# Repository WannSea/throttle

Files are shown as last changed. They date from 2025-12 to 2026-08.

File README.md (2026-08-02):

# WannSea Gashebel Firmware

Dieses Projekt nutzt das https://github.com/rp-rs/rp2040-project-template als Template.

## Installation

Rust über https://rustup.rs/ installieren und anschließend ausführen:

```sh
rustup target install thumbv6m-none-eabi
cargo install flip-link
cargo install --locked elf2uf2-rs
```

## Build

Es gibt zwei Möglichkeiten:

1. Den RP2040 mit gedrückter BOOTSEL-Taste per USB verbinden und die Firmware direkt bauen und flashen:

   ```sh
   cargo run
   ```

2. Eine UF2-Datei bauen, die später manuell auf das RP2040-USB-Laufwerk kopiert werden kann:

   ```sh
   cargo build --release
   elf2uf2-rs target/thumbv6m-none-eabi/release/rp2040-project-template throttle.uf2
   ```

## Info:

Green LED Blinking: Sending CAN throttle command
Red LED: Lever Locked

## Encoder / Hall

Der verwendete Encoder mit dem 5-poligen Stecker ist ein AS5600 und wird über I2C gelesen:

- Board-Stecker: `SDA`, `SCL`, `PWM/OUT`, `GND`, `3V3`
- Am AS5600: `VCC -> 3V3`, `GND -> GND`, `SDA -> SDA`, `SCL -> SCL`
- `DIR` habe ich fest mit `VCC` verbunden.
- `OUT/PWM` wird von der Firmware aktuell nicht benutzt.

## Veränderbare Parameter

Die wichtigsten Parameter stehen am Anfang von `src/main.rs`:

- `MAX_CURRENT_A`: maximal ausgegebener Strom bei vollständig ausgelenktem Gashebel, aktuell `500.0` A.
- `DELAY_MS`: Zeit zwischen zwei Ausgaben. `20` ms entsprechen 50 Hz.
- `ENCODER_ZERO_RAW`: Raw-Wert des Encoders in der neutralen Hebelposition.
- `ENCODER_FORWARD_MAX_RAW`: Raw-Wert bei vollständig nach vorne gedrücktem Gashebel.
- `ENCODER_REVERSE_MAX_RAW`: Raw-Wert bei vollständig nach hinten gedrücktem Gashebel.
- `ENCODER_DEADZONE_COUNTS`: Totzone von der Neutralstellung aus in jede Richtung. `50` bedeutet ungefähr 100 Counts Gesamttotzone.
- `PRETEND_HALL_PIN_ON`: Bei `true` wird der Hall-/Kill-Cord-Eingang für Tests als dauerhaft vorhanden behandelt.
- `ENABLE_USB_LOGGING`: Aktiviert bei `true` die Ausgabe der Encoderwerte über USB-Serial.

Die Encoder-Endwerte dürfen je nach Einbaurichtung des Sensors größer oder kleiner als `ENCODER_ZERO_RAW` sein. Entscheidend ist, dass die Werte an den tatsächlichen Endpositionen des Hebels eingetragen werden.

## USB-Debug-Ausgabe

Bei aktiviertem `ENABLE_USB_LOGGING` wird beispielsweise folgende Zeile ausgegeben:

```text
encoder raw: 2237, throttle_milli: 0, can: 00000116#00000000
```

Die drei Werte bedeuten:

- `encoder raw`: unverarbeiteter 12-Bit-Messwert des AS5600 von `0` bis `4095`.
- `throttle_milli`: aus Kalibrierung und Totzone berechnete Gasstellung. `-1000` entspricht dem einen Endanschlag, `0` der Neutralstellung und `+1000` dem anderen Endanschlag.
- `can`: Vorschau der tatsächlich gesendeten CAN-Nachricht im Format `CAN-ID#Payload`. `00000116` ist die `SetCurrent`-Nachricht für VESC-ID 22. Der achtstellige Payload enthält den vorzeichenbehafteten Stromwert als Ampere × 1.000. Im gesperrten Zustand ist dieser Payload immer `00000000`.

## SetDuty- und SetCurrent-Version

| SetDuty-Version | Aktuelle SetCurrent-Version |
|---|---|
| VESC `SetDuty`, CAN-ID `0x16` | VESC `SetCurrent`, CAN-ID `0x116` |
| Payload: vorzeichenbehafteter Duty-Wert von −100.000 bis +100.000 | Payload: vorzeichenbehafteter Stromwert von −500.000 bis +500.000 (Ampere × 1.000) |
| 50 Werte großes Glättungsfenster | Keine Glättung und keine Rampe |
| Vollständige Rampe dauert ca. 1 Sekunde | Ausgang folgt dem Gashebel unmittelbar |
| Ausgabe alle 20 ms / 50 Hz | Ausgabe alle 20 ms / 50 Hz |
| Null und der gesperrte Zustand werden explizit gesendet | Null und der gesperrte Zustand werden explizit gesendet |
| Encoder- und Hall-Auswertung wie in der aktuellen Version | Encoder- und Hall-Auswertung unverändert |

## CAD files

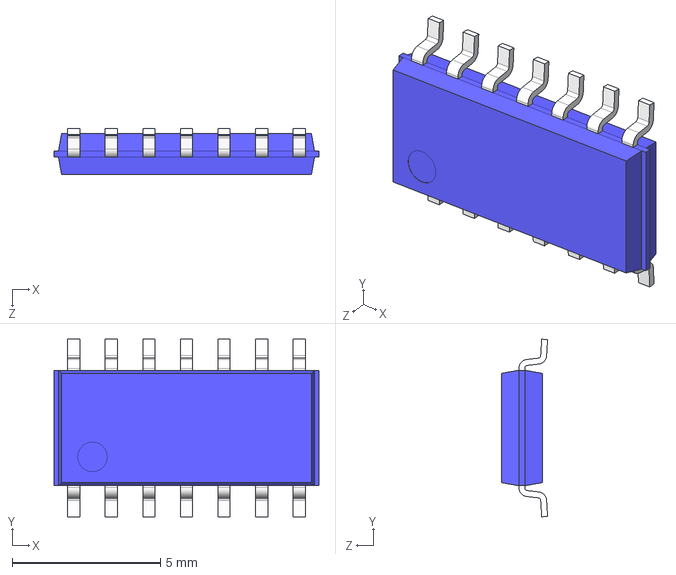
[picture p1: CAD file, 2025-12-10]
gashebel/1C23_powertrain_3D_models/SOIC14.STEP
8.95 x 6.00 x 1.56 mm

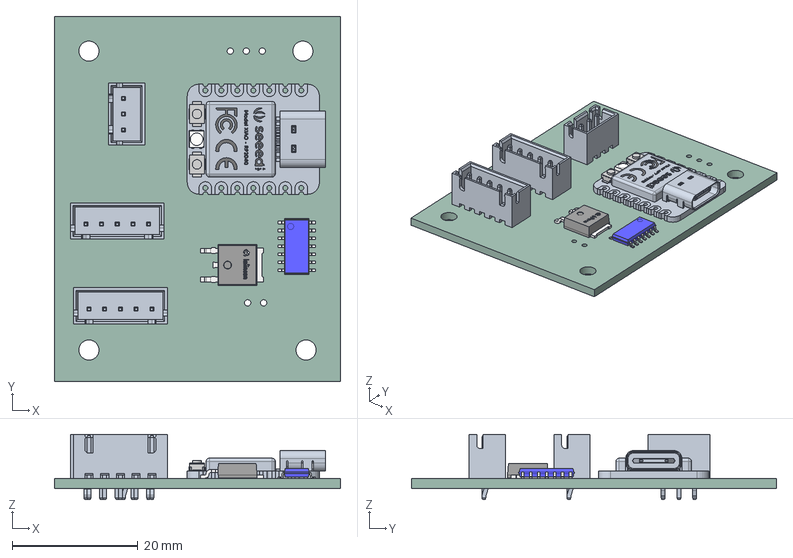
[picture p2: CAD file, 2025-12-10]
gashebel/gashebelboard.step
45.5 x 58.0 x 10.4 mm
B5B-XH-A x 2
B3B-XH-A
Product
Seeed Studio XIAO RP2040 v26
SOIC14
gashebelboard_PCB

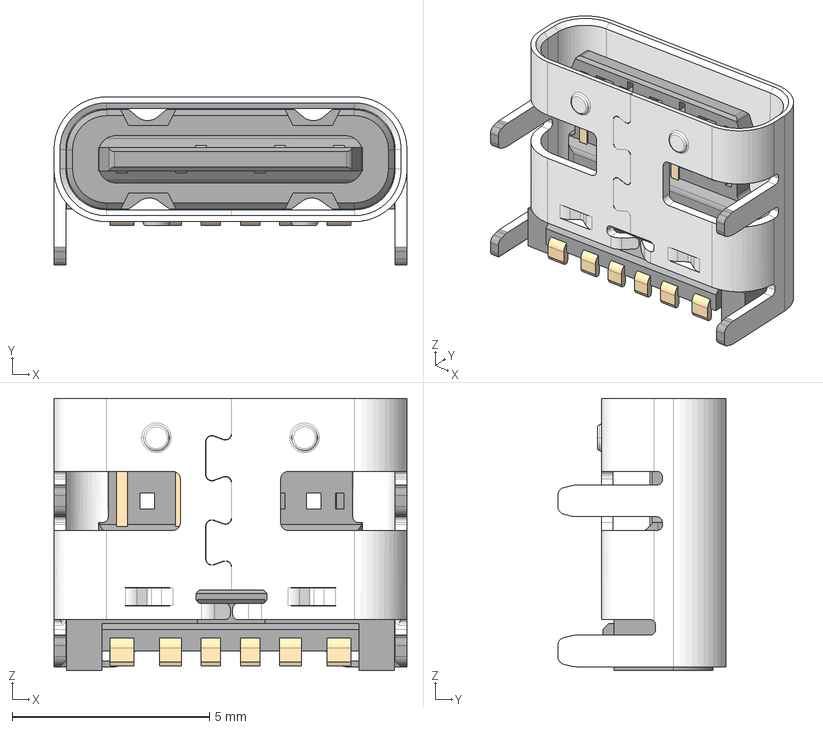
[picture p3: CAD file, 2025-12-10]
gashebel/1C23_powertrain_3D_models/USB4125-GF-A.stp
8.94 x 4.26 x 6.90 mm

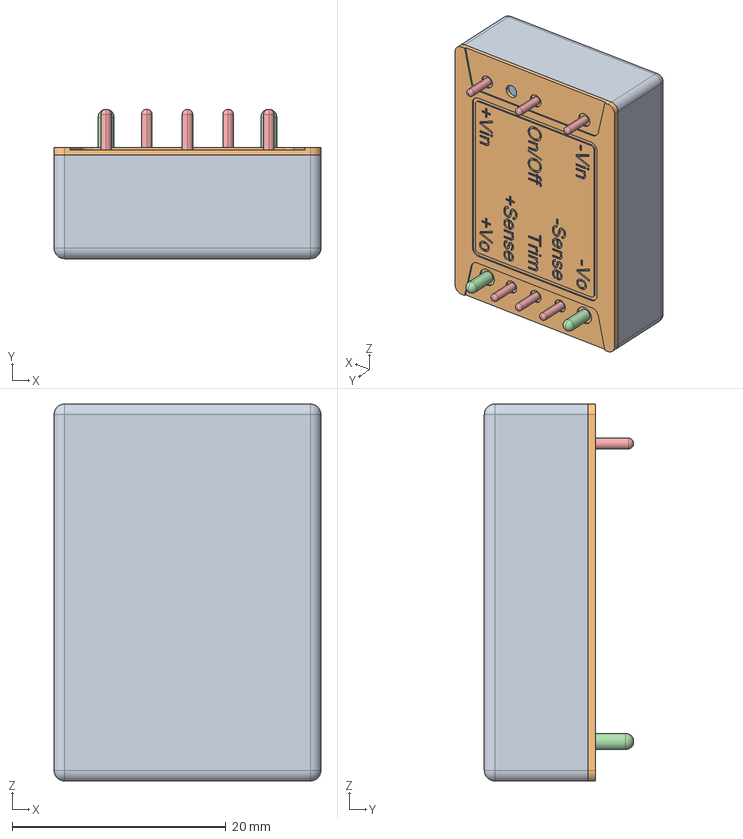
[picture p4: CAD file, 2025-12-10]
gashebel/1C23_powertrain_3D_models/PKU5500S.stp
25.0 x 14.0 x 35.3 mm
CU-CASE
BASE-PLASTIC
PCB
PIN1-2 x 2
PIN1-1 x 6

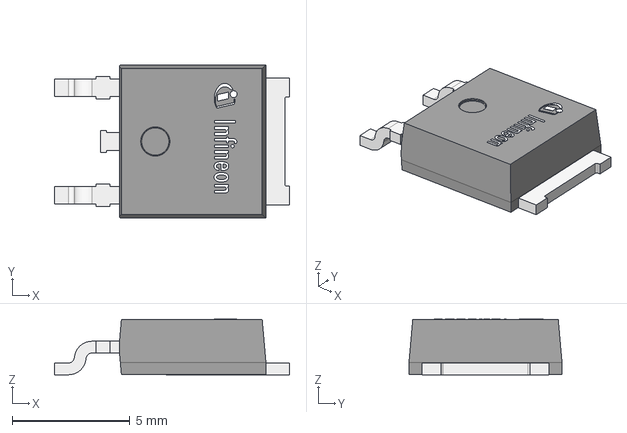
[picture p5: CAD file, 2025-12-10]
gashebel/1C23_powertrain_3D_models/Infineon-PG-TO252-3-11_3D_01_STP-Package-v05_00-EN.stp
9.98 x 6.50 x 2.36 mm

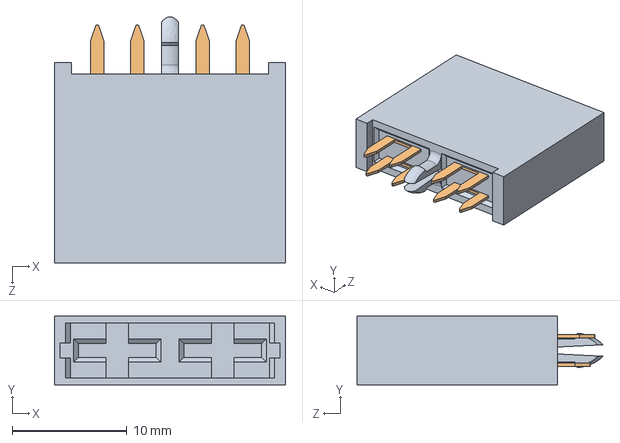
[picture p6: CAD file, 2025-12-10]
gashebel/1C23_powertrain_3D_models/178.6165.0000---Holder-FLR-(ATO)-Step-model.step
20.1 x 6.00 x 21.5 mm

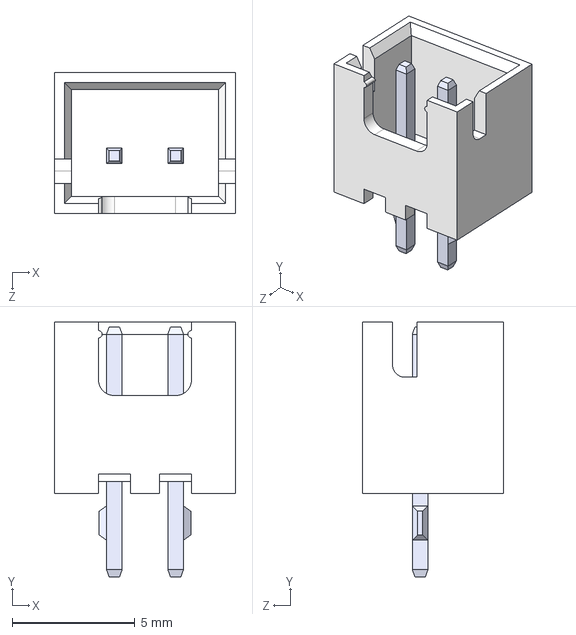
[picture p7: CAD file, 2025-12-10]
gashebel/1C23_powertrain_3D_models/B2B-XH-A.step
7.40 x 10.4 x 5.75 mm

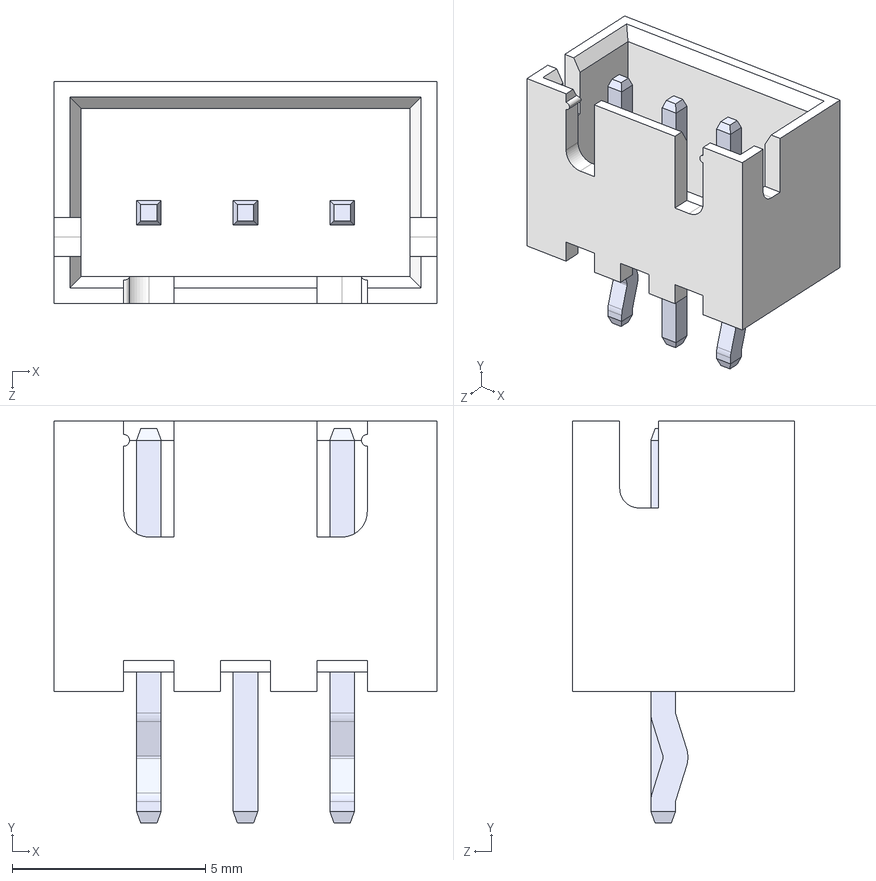
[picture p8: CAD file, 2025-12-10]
gashebel/1C23_powertrain_3D_models/B3B-XH-A.step
9.90 x 10.4 x 5.75 mm

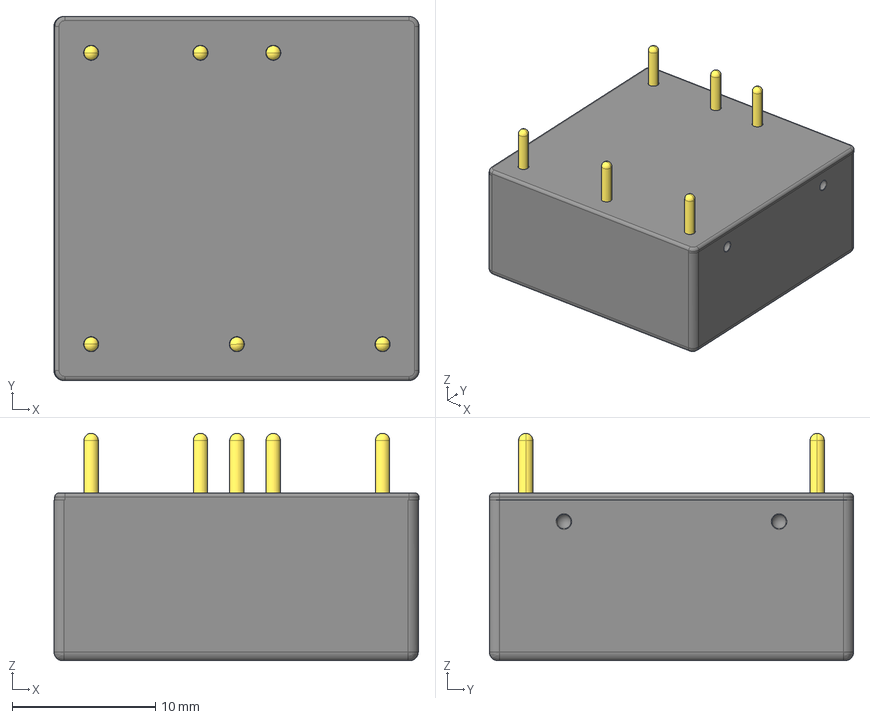
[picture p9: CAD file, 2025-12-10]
gashebel/1C23_powertrain_3D_models/URB_YMD-20WR3.stp
25.5 x 25.4 x 15.9 mm
MANIFOLD_SOLID_BREP_442_1
MANIFOLD_SOLID_BREP_826_1
MANIFOLD_SOLID_BREP_1210_1
MANIFOLD_SOLID_BREP_1594_1
MANIFOLD_SOLID_BREP_1978_1 x 2
MANIFOLD_SOLID_BREP_9091_1

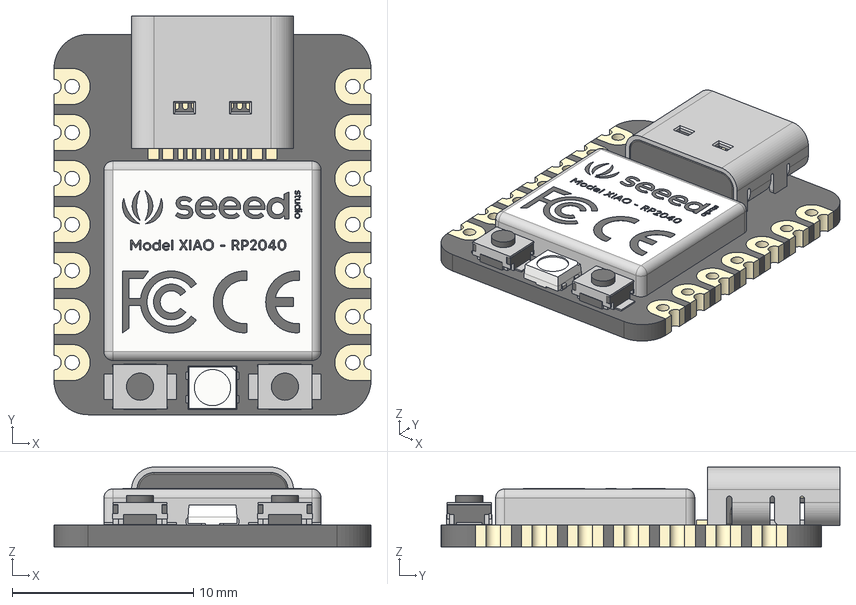
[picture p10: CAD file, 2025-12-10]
gashebel/1C23_powertrain_3D_models/Seeed Studio XIAO RP2040 v26.step
17.5 x 22.0 x 4.40 mm
type-c v2
smd_button v3
DOUT
DIN
VSS
VDD
smd_button v3(Mirror)

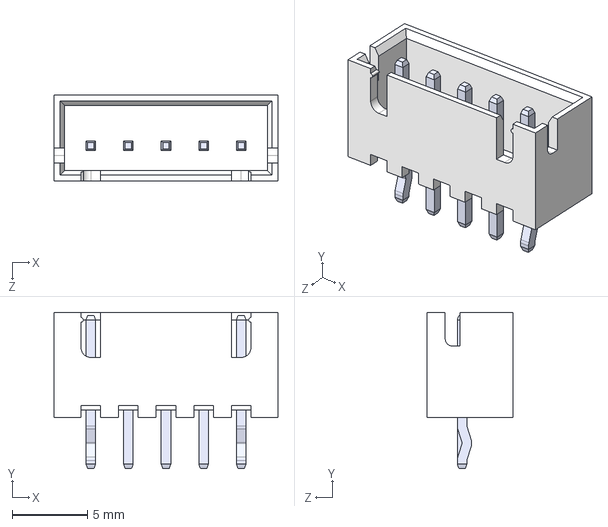
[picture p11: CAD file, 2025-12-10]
gashebel/1C23_powertrain_3D_models/B5B-XH-A.step
14.9 x 10.4 x 5.75 mm

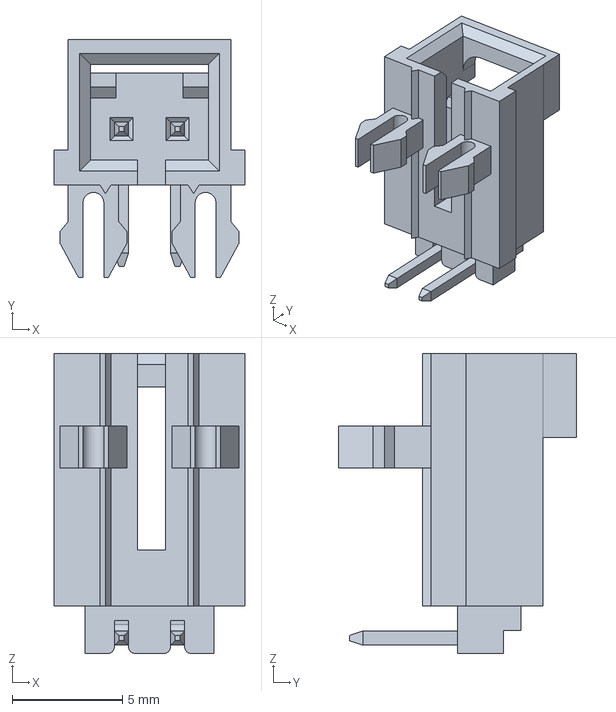
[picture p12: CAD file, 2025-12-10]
gashebel/1C23_powertrain_3D_models/705510036.stp
8.63 x 10.8 x 13.6 mm

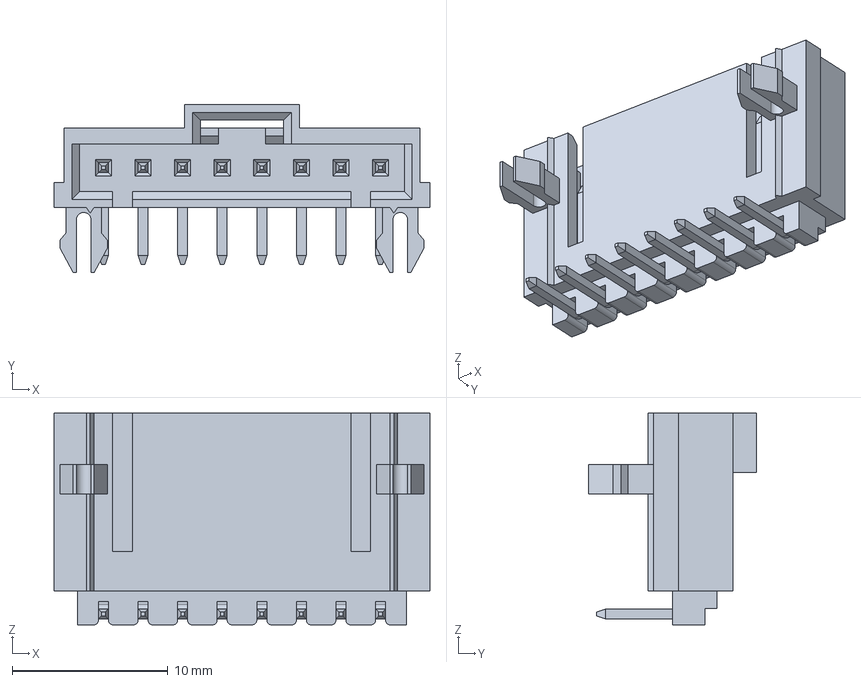
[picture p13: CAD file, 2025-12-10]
gashebel/1C23_powertrain_3D_models/705510042.stp
24.1 x 10.8 x 13.6 mm

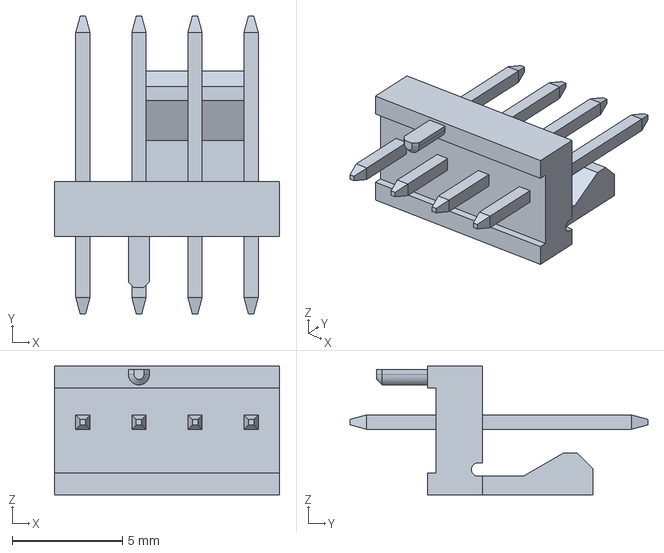
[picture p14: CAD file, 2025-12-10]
gashebel/1C23_powertrain_3D_models/470531000.stp
10.2 x 13.5 x 5.84 mm

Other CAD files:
gashebel/1C23_powertrain_3D_models/2741400000.stp
gashebel/1C23_powertrain_3D_models/705510038.stp
gashebel/1C23_powertrain_3D_models/705510037.stp
gashebel/1C23_powertrain_3D_models/705510040.stp

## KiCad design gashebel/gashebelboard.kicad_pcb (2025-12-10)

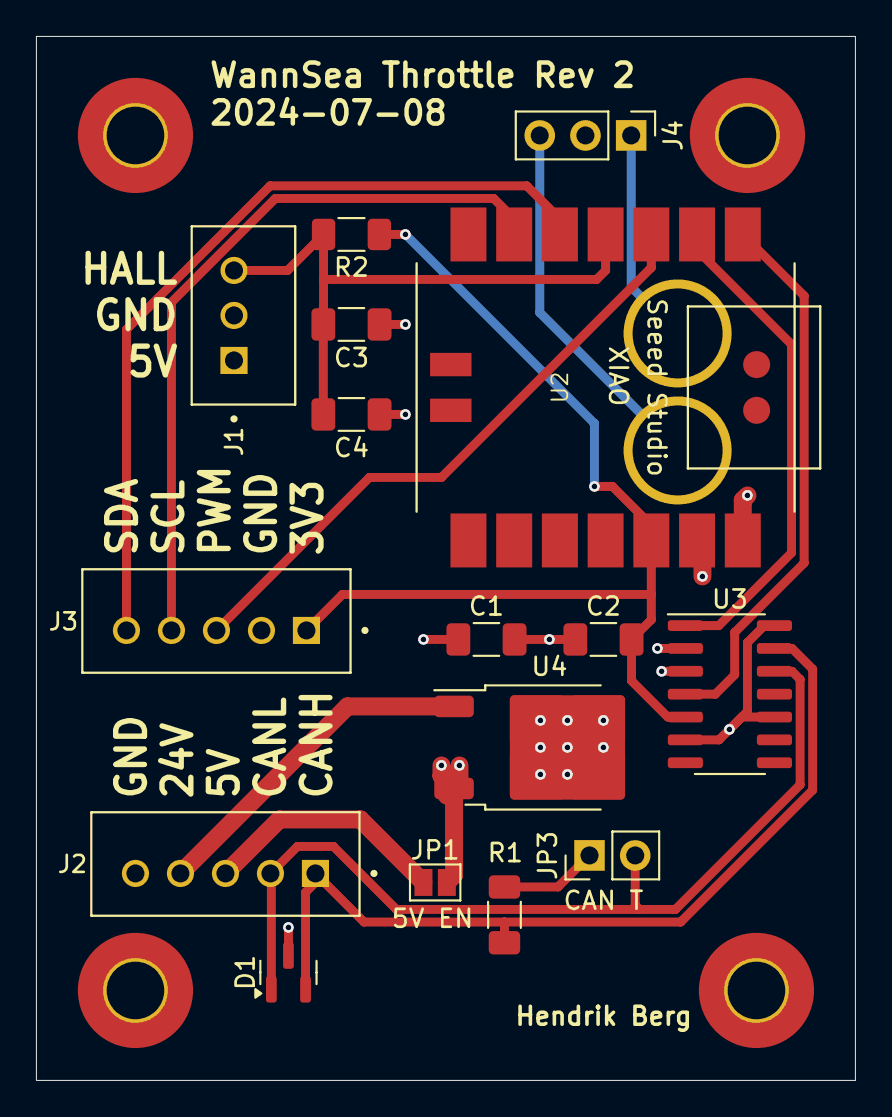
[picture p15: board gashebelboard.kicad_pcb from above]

Board: 4 copper layers, 45.5 x 58.0 mm, 20 parts (0 on the bottom side), 16 nets.

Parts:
C1, C2: 10µ; C_1206_3216Metric_Pad1.33x1.80mm_HandSolder
C3, C4: 4.7nF; C_1206_3216Metric_Pad1.33x1.80mm_HandSolder
D1: SM712_SOT23; SOT-23
H1, H2, H3, H4: MountingHole_Pad; MountingHole_3.2mm_M3_Pad_TopBottom
J1: Hall; JST_B3B-XH-A
J2: BOOT BUS; JST_B5B-XH-A
J3: ENCODER; JST_B5B-XH-A
J4: Conn_01x03_Pin; PinHeader_1x03_P2.54mm_Vertical
JP1: 5V EN; SolderJumper-2_P1.3mm_Open_Pad1.0x1.5mm
JP3: CAN T; PinHeader_1x02_P2.54mm_Vertical
R1: 120; R_1206_3216Metric_Pad1.30x1.75mm_HandSolder
R2: 1.2K; R_1206_3216Metric_Pad1.30x1.75mm_HandSolder
U2: Seeed Studio XIAO SAMD21; XIAO-SAMD21-RP2040-14P-2.54-21X17.8MM (Seeeduino XIAO)
U3: TJA1043T; SOIC-14_3.9x8.7mm_P1.27mm
U4: LM78M05_TO252; TO-252-2

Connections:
+3.3V: C2.2, J3.1, R2.1, U2.12 (3V3), U3.5 (VIO)
+5V: C1.1, C3.1, J1.1, JP1.2 (B), U2.14 (5V), U3.3 (VCC), U3.6 (EN), U3.10 (VBAT), U3.14 (~STB), U4.3 (VO)
/CAN_RX: U2.1 (PA02_A0_D0), U3.4 (RXD)
/CAN_TX: U2.2 (PA4_A1_D1), U3.1 (TXD)
/HALL: C3.2, C4.2, J1.3, R2.2, U2.4 (PA11_A3_D3)
/PWM: J3.3, U2.3 (PA10_A2_D2)
/SCL: J3.4, U2.6 (PA9_A5_D5_SCL)
/SDA: J3.5, U2.5 (PA8_A4_D4_SDA)
GND: C1.2, C2.1, C4.1, D1.3 (common), H1.1, H2.1, H3.1, H4.1, J1.2, J2.5, J3.2, J4.2, U2.13 (GND), U3.2 (GND), U4.2 (GND)
unnamed: D1.1 (A1), J2.2, JP3.2 (B), U3.12 (CANL)
unnamed: D1.2 (A2), J2.1, R1.1, U3.13 (CANH)
unnamed: J2.3, JP1.1 (A)
unnamed: J2.4, U4.1 (VI)
unnamed: J4.1, U2.17 (PA31_SWDIO)
unnamed: J4.3, U2.18 (PA30_SWCLK)
unnamed: JP3.1 (A), R1.2

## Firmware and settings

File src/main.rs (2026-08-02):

#![no_std]
#![no_main]

use alloc_cortex_m::CortexMHeap;
use bsp::entry;
use can2040::{Can2040, CanFrame};
use core::fmt::Write;
use defmt::*;
use defmt_rtt as _;
use embedded_can::nb::Can;
use embedded_can::{ExtendedId, Frame};
use embedded_hal::delay::DelayNs;
use embedded_hal::digital::{InputPin, OutputPin};
use embedded_hal::i2c::I2c;
use heapless::String;
use panic_probe as _;
use usb_device::{
    class_prelude::UsbBusAllocator,
    device::{StringDescriptors, UsbDevice},
    prelude::*,
};
use usbd_serial::SerialPort;

use seeeduino_xiao_rp2040 as bsp;

const CONFIG_CANBUS_FREQUENCY: u32 = 250_000;
const CONFIG_RP2040_CANBUS_GPIO_RX: u32 = 26;
const CONFIG_RP2040_CANBUS_GPIO_TX: u32 = 27;
const ENABLE_USB_LOGGING: bool = true;

#[global_allocator]
pub static ALLOCATOR: CortexMHeap = CortexMHeap::empty();

pub fn init_allocator() {
    // Please set the correct heap size.
    const HEAP_SIZE: usize = 0x8000;
    static mut HEAP: [u8; HEAP_SIZE] = [0; HEAP_SIZE];
    unsafe { ALLOCATOR.init(HEAP.as_ptr() as usize, HEAP.len()) }
}

use bsp::hal::{
    clocks::init_clocks_and_plls,
    fugit::RateExtU32,
    gpio::{FunctionI2C, Pin},
    pac,
    sio::Sio,
    usb::UsbBus,
    watchdog::Watchdog,
    Timer, I2C,
};

#[allow(dead_code)]
#[repr(u8)]
enum CanCommands {
    SetDuty = 0,
    SetCurrent = 1,
    SetCurrentBrake = 2,
    SetRpm = 3,
    SetPos = 4,
}

const VESC_ID: u32 = 22;
const CAN_ID_SET_CURRENT_RAW: u32 = (CanCommands::SetCurrent as u32) << 8 | VESC_ID;
const CAN_ID_SET_CURRENT: Option<ExtendedId> = ExtendedId::new(CAN_ID_SET_CURRENT_RAW);

const DELAY_MS: u32 = 20;
const MAX_CURRENT_A: f32 = 500.0;

// AS5600 magnetic encoder on the 5-pin connector
const AS5600_I2C_ADDRESS: u8 = 0x36;
const AS5600_RAW_ANGLE_REGISTER: u8 = 0x0C;

// Encoder calibration:
// 1. Put the throttle in neutral/rest position and copy the logged raw angle here.
// 2. Move the throttle in the desired forward direction and enter the value for FORWARD_MAX_RAW. Same for backwards.
// 3. Deadzone: the deadzone range from neutral into one direction (2 ways, so the total deadzone size is this value * 2)
const ENCODER_ZERO_RAW: u16 = 2237;
const ENCODER_DEADZONE_COUNTS: i32 = 50;
const ENCODER_FORWARD_MAX_RAW: u16 = 1687;
const ENCODER_REVERSE_MAX_RAW: u16 = 2790;

// Disable Safety Cord, pretend Kill Cord is always there
const PRETEND_HALL_PIN_ON: bool = false;

#[entry]
fn main() -> ! {
    init_allocator();
    info!("Program start");
    let mut pac = pac::Peripherals::take().unwrap();
    let mut core = pac::CorePeripherals::take().unwrap();
    let mut watchdog = Watchdog::new(pac.WATCHDOG);
    let sio = Sio::new(pac.SIO);

    // External high-speed crystal on the pico board is 12Mhz
    let clocks = init_clocks_and_plls(
        bsp::XOSC_CRYSTAL_FREQ,
        pac.XOSC,
        pac.CLOCKS,
        pac.PLL_SYS,
        pac.PLL_USB,
        &mut pac.RESETS,
        &mut watchdog,
    )
    .ok()
    .unwrap();

    let mut timer = Timer::new(pac.TIMER, &mut pac.RESETS, &clocks);

    let pins = bsp::Pins::new(
        pac.IO_BANK0,
        pac.PADS_BANK0,
        sio.gpio_bank0,
        &mut pac.RESETS,
    );

    let mut led_green = pins.led_green.into_push_pull_output();
    let mut led_red = pins.led_red.into_push_pull_output();

    // Configure two pins as being I²C, not GPIO
    let sda_pin: Pin<_, FunctionI2C, _> = pins.sda.reconfigure();
    let scl_pin: Pin<_, FunctionI2C, _> = pins.scl.reconfigure();

    // Create the I²C driver, using the two pre-configured pins. This will fail
    // at compile time if the pins are in the wrong mode, or if this I²C
    // peripheral isn't available on these pins!
    let mut i2c = I2C::i2c1(
        pac.I2C1,
        sda_pin,
        scl_pin,
        200.kHz(),
        &mut pac.RESETS,
        &clocks.peripheral_clock,
    );
    let mut can_bus = can2040::initialize_cbus(
        &mut core,
        CONFIG_CANBUS_FREQUENCY,
        CONFIG_RP2040_CANBUS_GPIO_RX,
        CONFIG_RP2040_CANBUS_GPIO_TX,
    );

    let mut hall_pin = pins.a3.into_floating_input();

    let usb_bus = if ENABLE_USB_LOGGING {
        Some(UsbBusAllocator::new(UsbBus::new(
            pac.USBCTRL_REGS,
            pac.USBCTRL_DPRAM,
            clocks.usb_clock,
            true,
            &mut pac.RESETS,
        )))
    } else {
        None
    };
    let mut serial = usb_bus.as_ref().map(SerialPort::new);
    let mut usb_dev = usb_bus.as_ref().map(|usb_bus| {
        UsbDeviceBuilder::new(usb_bus, UsbVidPid(0x16c0, 0x27dd))
            .strings(&[StringDescriptors::default()
                .manufacturer("WannSea")
                .product("Gashebel Setup Serial")
                .serial_number("throttle")])
            .unwrap()
            .device_class(2)
            .build()
    });

    let registers: [u8; 1] = [AS5600_RAW_ANGLE_REGISTER];
    let mut angle_buff: [u8; 2] = [0; 2];

    let mut engine_locked = true;

    loop {
        poll_usb_serial(&mut usb_dev, &mut serial);

        led_green.set_high().unwrap();
        // use rp-pico 0.9
        let (current, encoder_reading): (i32, Option<(u16, f32)>) =
            match i2c.write_read(AS5600_I2C_ADDRESS, &registers, &mut angle_buff) {
                Ok(_) => {
                    let angle = (((angle_buff[0] as u16) << 8) | angle_buff[1] as u16) & 0x0fff;
                    let throttle = throttle_from_angle(angle);
                    let offset = encoder_offset(angle);
                    info!(
                        "encoder raw: {}, offset: {}, throttle: {}",
                        angle, offset, throttle
                    );
                    (current_from_throttle(throttle), Some((angle, throttle)))
                }
                Err(_e) => {
                    warn!("could not read from i2c");
                    write_usb_line(&mut serial, "could not read from i2c\r\n");
                    (0, None)
                }
            };

        let kill_cord_present = if PRETEND_HALL_PIN_ON {
            true
        } else {
            match hall_pin.is_low() {
                Ok(is_low) => is_low,
                Err(_) => false,
            }
        };

        if !kill_cord_present {
            engine_locked = true;
        }

        if kill_cord_present && current == 0 {
            engine_locked = false;
        }

        let transmit_current = if engine_locked {
            led_red.set_low().unwrap();
            0
        } else {
            led_red.set_high().unwrap();
            current
        };

        info!("current: {}", transmit_current);
        if let Some((angle, throttle)) = encoder_reading {
            write_usb_encoder_log(&mut serial, angle, throttle, transmit_current);
        }

        let frame =
            CanFrame::new(CAN_ID_SET_CURRENT.unwrap(), &transmit_current.to_be_bytes()).unwrap();
        let _ = <Can2040 as Can>::transmit(&mut can_bus, &frame)
            .inspect_err(|_e| warn!("CAN TX error would block: dropping Frame"));

        delay_ms_maybe_usb_poll(&mut timer, &mut usb_dev, &mut serial, DELAY_MS / 2);
        led_green.set_low().unwrap();
        delay_ms_maybe_usb_poll(&mut timer, &mut usb_dev, &mut serial, DELAY_MS / 2);
    }
}

fn delay_ms_maybe_usb_poll(
    timer: &mut Timer,
    usb_dev: &mut Option<UsbDevice<UsbBus>>,
    serial: &mut Option<SerialPort<UsbBus>>,
    ms: u32,
) {
    if !ENABLE_USB_LOGGING {
        timer.delay_ms(ms);
        return;
    }

    for _ in 0..ms {
        poll_usb_serial(usb_dev, serial);
        timer.delay_ms(1);
    }
}

fn poll_usb_serial(
    usb_dev: &mut Option<UsbDevice<UsbBus>>,
    serial: &mut Option<SerialPort<UsbBus>>,
) {
    let (Some(usb_dev), Some(serial)) = (usb_dev.as_mut(), serial.as_mut()) else {
        return;
    };

    if usb_dev.poll(&mut [serial]) {
        let mut buf = [0u8; 64];
        let _ = serial.read(&mut buf);
    }
}

fn write_usb_encoder_log(
    serial: &mut Option<SerialPort<UsbBus>>,
    angle: u16,
    throttle: f32,
    transmit_current: i32,
) {
    if !ENABLE_USB_LOGGING {
        return;
    }

    let mut line: String<128> = String::new();
    let throttle_milli = (throttle * 1000.0) as i32;
    let _ = writeln!(
        &mut line,
        "encoder raw: {}, throttle_milli: {}, can: {:08X}#{:08X}\r",
        angle, throttle_milli, CAN_ID_SET_CURRENT_RAW, transmit_current as u32
    );
    write_usb_line(serial, line.as_str());
}

fn write_usb_line(serial: &mut Option<SerialPort<UsbBus>>, line: &str) {
    if let Some(serial) = serial.as_mut() {
        let _ = serial.write(line.as_bytes());
    }
}

fn current_from_throttle(throttle: f32) -> i32 {
    (throttle.clamp(-1.0, 1.0) * MAX_CURRENT_A * 1000.0) as i32
}

fn throttle_from_angle(angle: u16) -> f32 {
    let offset = encoder_offset(angle);

    if offset.abs() <= ENCODER_DEADZONE_COUNTS {
        return 0.0;
    }

    let throttle = if offset > 0 {
        (offset - ENCODER_DEADZONE_COUNTS) as f32
            / (encoder_offset(ENCODER_FORWARD_MAX_RAW).abs() - ENCODER_DEADZONE_COUNTS) as f32
    } else {
        (offset + ENCODER_DEADZONE_COUNTS) as f32
            / (encoder_offset(ENCODER_REVERSE_MAX_RAW).abs() - ENCODER_DEADZONE_COUNTS) as f32
    };

    throttle.clamp(-1.0, 1.0)
}

fn encoder_offset(angle: u16) -> i32 {
    angle as i32 - ENCODER_ZERO_RAW as i32
}

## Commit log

2024-07-02 adjust throttle map
2025-12-10 add schematics
    [178.6165.0000---Holder-FLR-(ATO)-Step-model.step, 2741400000.stp, 470531000.stp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]
2026-06-18 Calibration guide added
2026-06-18 Duty ersetzt durch erpm und current
2026-06-18 Reverse and forward different accellerations
    [main.rs]
2026-06-21 Hall sensor check toggle
2026-07-02 working duty version, wrong offsets
    [main.rs]
2026-07-07 Limits calibrated to mebc 26 beginning state
2026-07-07 set current implemented with 300A max motor current
2026-07-09 calibration fixed
2026-07-30 duty with correct calibration
    [main.rs]
2026-08-02 ÜBERGABE: Hendricks SetDuty Version für den neuen Hebel mit minimalen Fixes (siehe Readme)
    [main.rs]

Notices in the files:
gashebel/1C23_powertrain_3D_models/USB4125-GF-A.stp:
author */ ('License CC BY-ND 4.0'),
